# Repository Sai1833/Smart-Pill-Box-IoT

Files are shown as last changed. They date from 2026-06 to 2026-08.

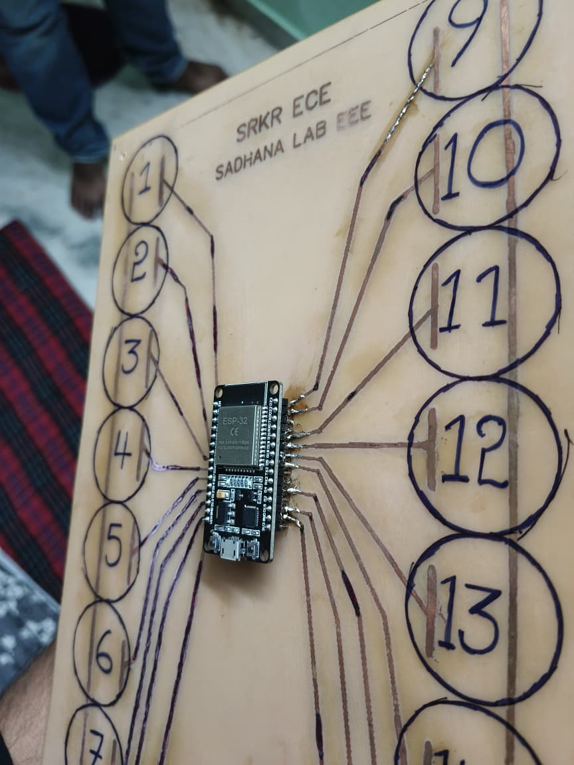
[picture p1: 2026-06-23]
03-PCB_Design/PCB_Hardware/PCB_with_Sholdered_MC_img02.jpg

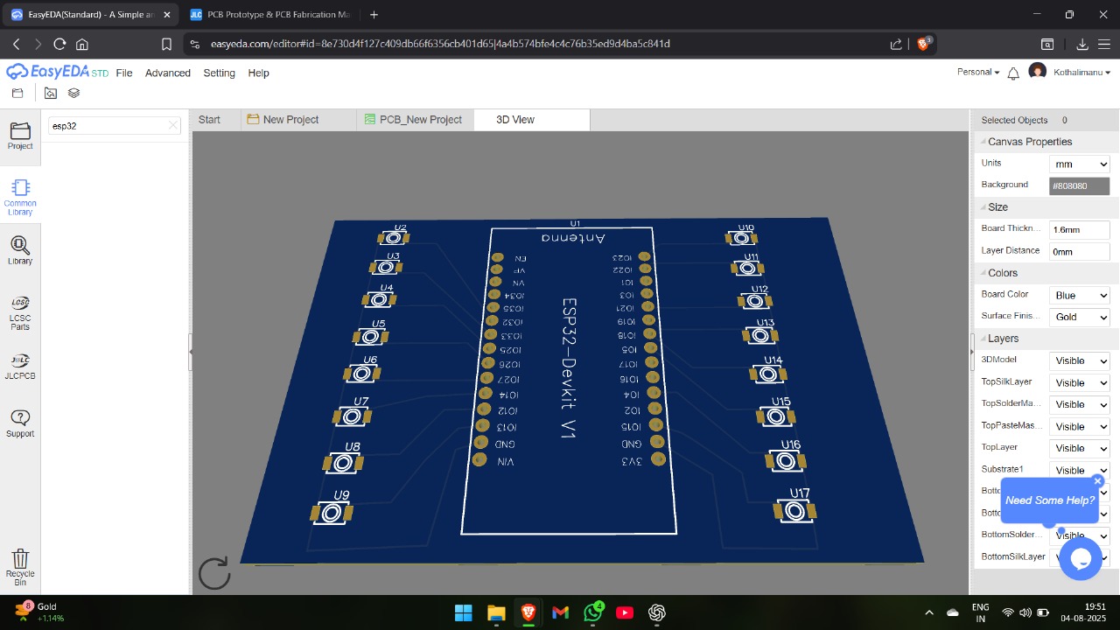
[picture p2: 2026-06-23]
03-PCB_Design/PCB_Simulation/PCB_Design_EasyEda_img01.jpg

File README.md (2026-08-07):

# <p align="center"> 💊 Smart QR Pill Box – IoT Project </p>
## <p align="center">  ESP32 + Bluetooth | End-to-End Product </p>

<p align="center">
  
  
  
  
  
</p>

<p align="center">
  <b>A complete smart medication monitoring system designed, fabricated, assembled, and delivered as a working product.</b><br>
  From sensor research → PCB design & manual fabrication → 3D enclosure → battery integration → final tested unit.
</p>

---

## 🌟 Project Vision

Medication non-adherence is a silent global problem.  
This **Smart QR Pill Box** was built to solve it with a practical, portable, and intelligent American-style design.

The system detects when pills are taken from individual compartments and communicates the status via **Bluetooth**, enabling real-time monitoring and future smart features.

---

## ✨ Key Highlights

| Feature | Details |
|---|---|
| 📦 **10 Pill Bays** | Final production-ready 10-slot design |
| 📡 **Bluetooth Connectivity**  | Real-time status via ESP32 Bluetooth |
| 🔋 **Rechargeable Power** | 3.7V Li-Ion + TP4060 + MT3608 boost |
| 🛠️ **Custom PCB** | Schematic → Layout → Manual etching → Soldering |
| 🖨️ **3D Enclosure** | AutoCAD designed + Laser-cut acrylic finish |
| 📱 **QR Ready** | Designed for QR-based medicine identification |
| 🧪 **Fully Tested** | Office-level validation + final product delivery |

---

## 🧠 How It Works

Pill Taken → Conductive detection (Aluminium foil) → ESP32 senses change → 
Bluetooth transmits status → Companion device / future app receives data

The bottom of each compartment uses aluminium foil as a conductive layer. When a pill bottle or compartment is accessed, the system registers the change and updates the status over Bluetooth.

---

## 🔌 Hardware Stack

- **Microcontroller**: ESP32 DevKit V1
- **Connectivity**: Bluetooth
- **Power System**:
  - 3.7V Li-Ion / LiPo battery
  - TP4060 charging module
  - MT3608 boost converter
- **Detection**: Aluminium foil conductive layer
- **Enclosure**: Custom 3D-designed + Laser-cut acrylic (blue shiny finish)
- **PCB**: Multiple versions designed & fabricated (final 10-slot)

---

## 🛠️ Complete Product Development Journey

| Phase | What Was Done | Outcome |
|---|---|---|
| **Research** | Sensor study, QR concept, LLM/SLM feasibility | Technology selection |
| **Simulation** | Multi-configuration circuits (6/10-way) | Validated sensing methods |
| **Prototyping** | Cardboard models + component assembly | Working proof-of-concept |
| **PCB Design** | Schematic → Layout → Dimension optimization | Multiple PCB revisions |
| **Manual Fabrication** | Toner transfer + FeCl₃ etching + drilling | Hands-on PCB manufacturing  |
| **Assembly** | ESP32 soldering + conductive interface | Fully functional hardware |
| **3D Design** | Base, top, phone holder, slot alignment | Enclosure ready for printing|
| **Power Integration**  | Battery + charging + boost modules | Portable & rechargeable |
| **Final Assembly** | Fitting, adhesives, laser cutting, aesthetics | Product-level finish |
| **Testing & Delivery** | Office testing + courier to Pune office | Successfully delivered |

---

## 💻 Firmware

Located in `07-Code/`

The firmware runs on ESP32 and handles:
- Pill compartment status detection
- Bluetooth communication
- Real-time status reporting

> Update credentials as needed before flashing.

---

## 📸 Project Gallery

Explore the full visual journey:

- **Simulations** → `01-Simulations/`
- **Early Prototypes** → `02-Prototype/`
- **PCB Fabrication Process** → `03-PCB_Design/PCB_Hardware/`
- **3D Designs** → `04-3D_Design/`
- **Final Product** → `05-Final_output/`

---

## 🚀 Future Roadmap

- [ ] Mobile App (Bluetooth pairing + medication schedule)
- [ ] QR code scanning for medicine identification
- [ ] Cloud logging & caregiver dashboard
- [ ] Missed dose alerts & reminders
- [ ] LLM/SLM assisted smart suggestions
- [ ] Multi-user support

---

## 👨‍💻 Contributors

<table>
  <tr>
    <td align="center">
      <a href="https://github.com/Sai1833">
        Sai<br>
        <b>Sai Prakash</b>
      </a>
    </td>
    <td align="center">
      <a href="https://github.com/manohar0306-art">
        Manohar<br>
        <b>Manohar</b>
      </a>
    </td>
    <td align="center">
      <a href="https://github.com/Bhanu-79">
        Bhanu<br>
        <b>Bhanu</b>
      </a>
    </td>
  </tr>
</table>

---

**Internship Details**  
**Company**: Blue Planet Infosolutions Pvt Ltd (Pan Health)  
**Domain**: Embedded System Development  
**Duration**: June 2025 – December 2025  
**Mentor**: Avi Kulkarni Sir  

---

## 📄 Documentation

Full internship completion report and task-wise attachments are available in the  
[`06-Documentations`](./06-Documentations) folder.

---

<p align="center">
  <b>Built with precision. Tested in real conditions. Delivered as a product.</b><br>
  <i>Helping people never miss their medicine — one smart box at a time.</i>
</p>

<p align="center">
  ★ Star this repository if you find it useful ★
</p>

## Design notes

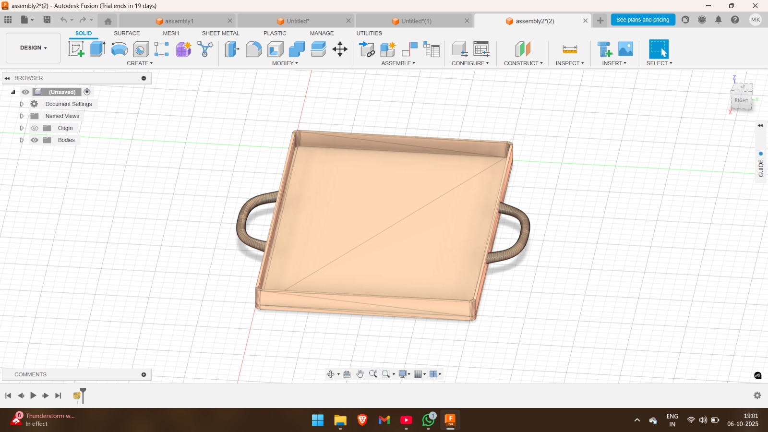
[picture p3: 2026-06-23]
04-3D_Design/Autocad_3D_Design_Bottom_img01.jpg

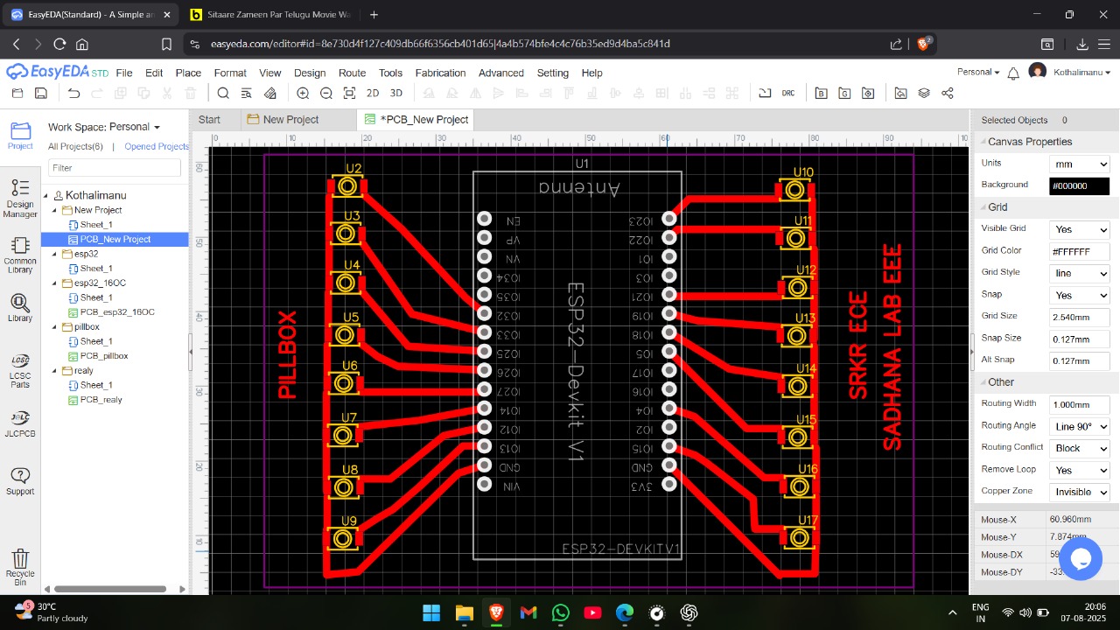
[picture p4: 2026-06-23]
03-PCB_Design/PCB_Simulation/PCB_Design_EasyEda_img03.jpg

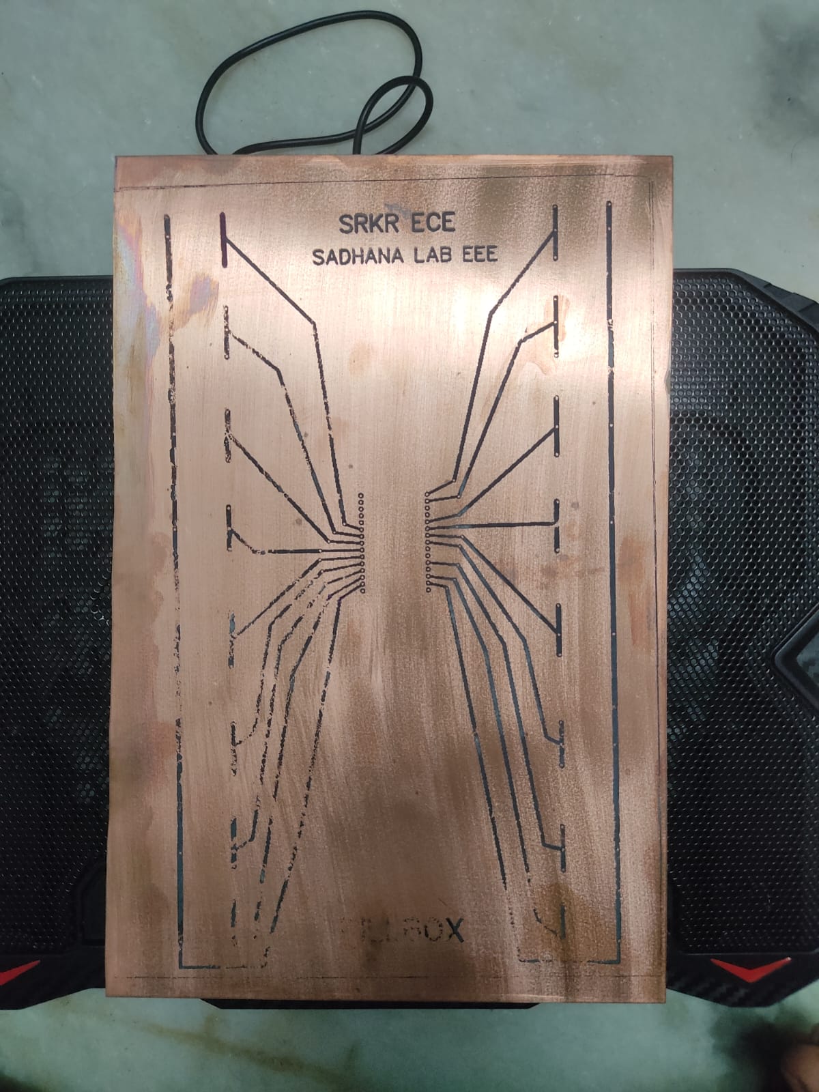
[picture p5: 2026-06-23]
03-PCB_Design/PCB_Hardware/PCB_Before_Removing_Copper_img02.jpg

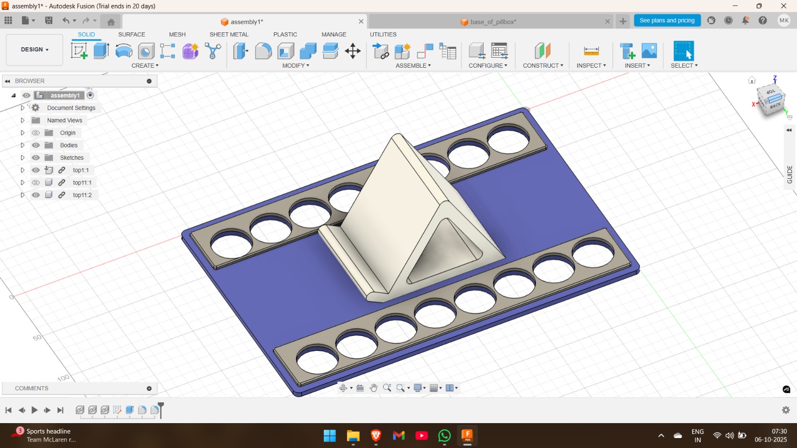
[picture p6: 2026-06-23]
04-3D_Design/Autocad_3D_Design_Top_img01.jpg

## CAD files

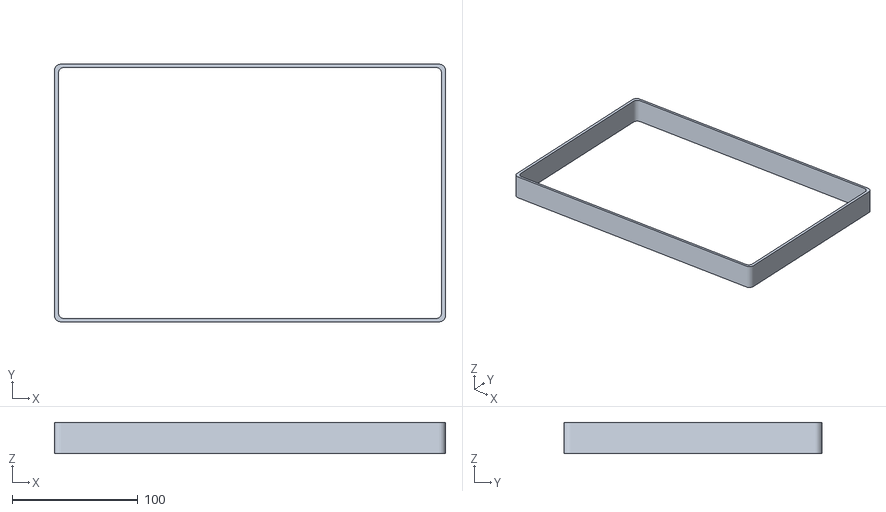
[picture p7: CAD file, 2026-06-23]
04-3D_Design/3D_Design_Cad_Files/center1.stl
311.0 x 205.0 x 25.0

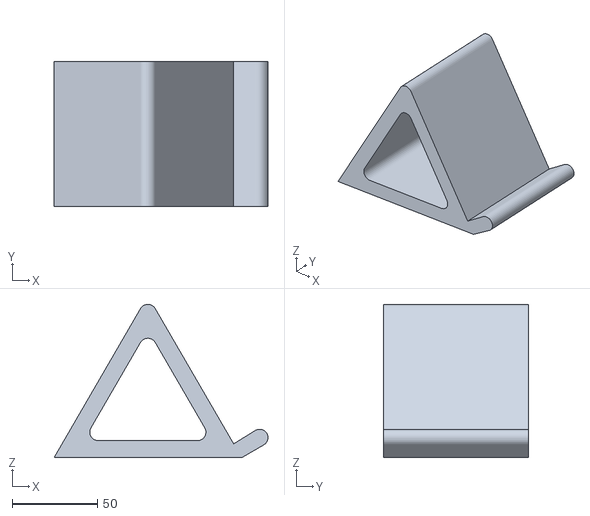
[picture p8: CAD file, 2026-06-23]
04-3D_Design/3D_Design_Cad_Files/top11.stl
125.8 x 85.0 x 90.2

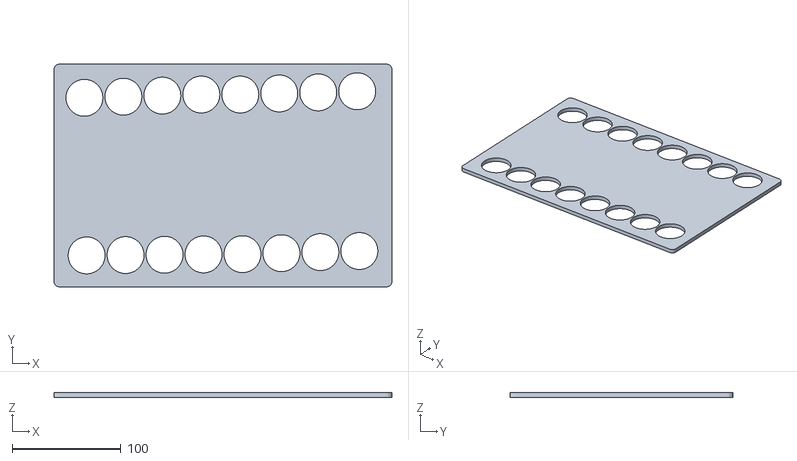
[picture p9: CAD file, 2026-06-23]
04-3D_Design/3D_Design_Cad_Files/top1.stl
311.0 x 205.0 x 4.50

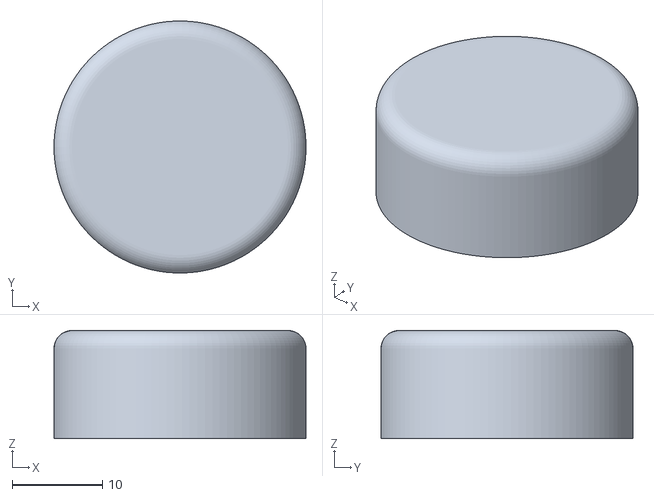
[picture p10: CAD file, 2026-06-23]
04-3D_Design/3D_Design_Cad_Files/bottle_cap.stl
28.0 x 28.0 x 12.0

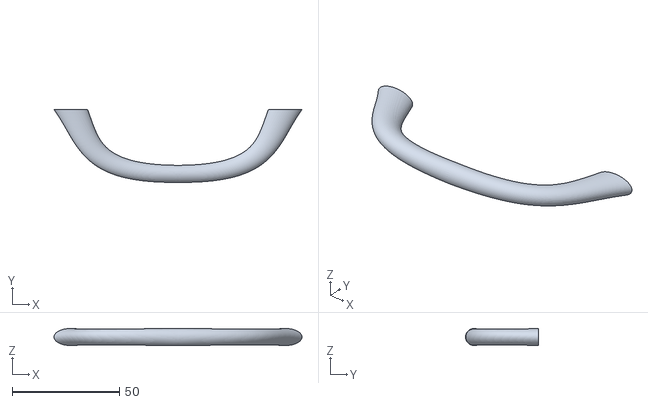
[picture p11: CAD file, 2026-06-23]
04-3D_Design/3D_Design_Cad_Files/handel1.stl
115.7 x 34.0 x 8.00

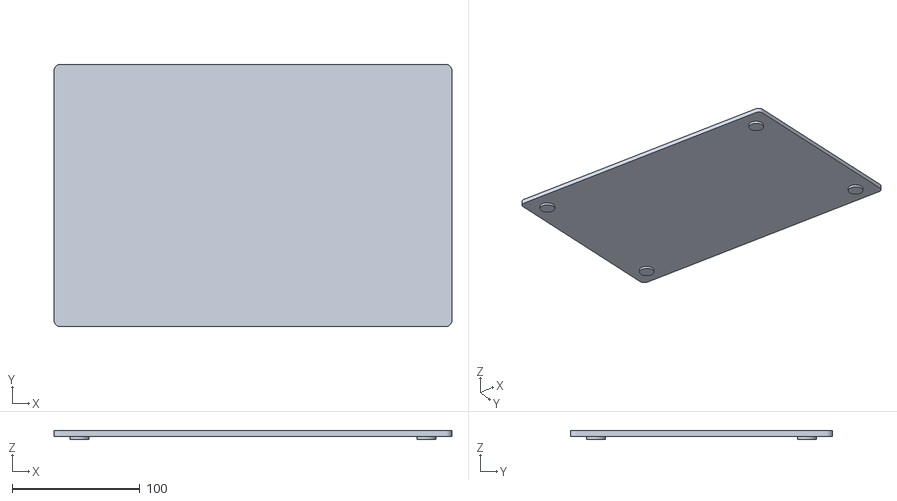
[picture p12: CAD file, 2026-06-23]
04-3D_Design/3D_Design_Cad_Files/bottom1.stl
311.0 x 205.0 x 7.00

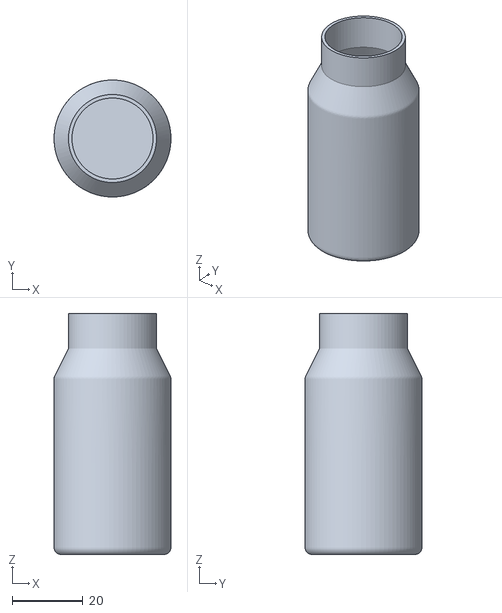
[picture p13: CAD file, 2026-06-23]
04-3D_Design/3D_Design_Cad_Files/bottle_bottom.stl
33.0 x 33.0 x 68.0

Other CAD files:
04-3D_Design/3D_Design_Cad_Files/bottle_bottom.f3z
04-3D_Design/3D_Design_Cad_Files/bottle_cap.f3d
04-3D_Design/3D_Design_Cad_Files/bottom1.f3d
04-3D_Design/3D_Design_Cad_Files/center1.f3d
04-3D_Design/3D_Design_Cad_Files/handel1.f3d
04-3D_Design/3D_Design_Cad_Files/top1.f3d
04-3D_Design/3D_Design_Cad_Files/top11.f3d

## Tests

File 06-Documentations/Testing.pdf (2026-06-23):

REPORT ON TESTING OF SMART PILLBOX By Anishka Tiwari
Date of Testing: 3 December 2025
Team Present: IN Google meet
- Sanvi Kothi
- Manhora
- Sai Prakash
- Anishka

## 1. Introduction

The purpose of this testing session was to evaluate the functioning, connectivity, and reliability of the smart pillbox prototype. The device had been previously shipped to us, and this round of testing was intended to verify basic hardware operation, power system behavior, ESP microcontroller activity, and Bluetooth data communication.

This report documents the observations, issues identified, troubleshooting steps performed, and partial outcomes achieved during the session conducted on 3 December 2025.

## 2. Initial Setup and Power-On Attempts

At the beginning of the test, the team faced difficulty in powering on the smart pillbox. The device did not respond on initial attempts to activate it. After examining the physical structure, the team applied pressure on the yellow lid, suspecting a loose power connection.

Upon pressing the lid and connecting the device to a USB-C charging port, the pillbox displayed a blue activation indicator, confirming that some portion of the power system was active.
However, despite this LED response, the ESP module did not show any signs of functioning, indicating a deeper issue in internal circuitry or power delivery.

## 3. Inspection of Internal Components

To investigate the cause behind the ESP’s non-responsiveness, the team proceeded to open the blue plastic lid of the pillbox.

### 3.1 Findings

- Inside the pillbox, the battery’s ground wire was found to be distorted or loose, most likely due to mishandling or vibration during shipping.
- This faulty ground connection prevented stable power supply to the internal circuit.
- As a result, the ESP microcontroller remained inactive even when the external USB-C port showed a charging indicator.

Identifying this fault confirmed that the issue was hardware-related and not due to firmware malfunction.

## 4. ESP Functionality Testing

To further confirm whether the ESP module was operational, it was removed from the pillbox power line and tested independently.

### 4.1 Procedure

- The ESP board was connected directly to a computer using a USB-B cable.
- This ensured stable external power and allowed direct serial communication for testing.

### 4.2 Result

- The ESP powered on through the USB-B connection.
- This verified that the ESP board itself was not damaged.

Thus, the primary cause of non-functionality was confirmed to be the broken ground connection inside the pillbox.

## 5. Bluetooth Connectivity Tests

### 5.1 Testing via Android Teams App (Bluetooth Admin)

- The team attempted pairing and communication using the Android Teams Bluetooth Admin app.
- While the app could detect the device intermittently, it failed to read or transmit any data.
- This indicated incomplete or unstable Bluetooth communication.

### 5.2 Testing via Custom Smartphone App

- The pillbox was then tested using the custom app developed for the project.
- The custom app successfully detected the Bluetooth module, confirming that the device was broadcasting.
- However, no data packets were received, indicating either:
- a serial communication issue between ESP and Bluetooth module, or
- unstable power supply because of the internal wiring fault.

### 5.3 Testing via Third-Party App: Serial Bluetooth Terminal

- A third-party application named “Serial Bluetooth” from the Play Store was used.
- All available Bluetooth slots were scanned.
- The app initially failed to detect stable internal BC signals, again due to power instability.
- After multiple attempts, partial detections occurred, showing that the module was broadcasting but not fully functional.

These tests collectively verified that the Bluetooth module was functional but could not maintain stable communication due to internal wiring and power issues.

## 6. Conclusion

The testing session on 3 December 2025 revealed that the smart pillbox suffered from a critical internal power connection failure, specifically a distorted or loose battery ground wire caused during shipping. This resulted in:

- ESP microcontroller failing to boot through onboard power
- Unstable Bluetooth communication
- Intermittent device activation despite USB-C charging indicator

Independent testing confirmed that the ESP and Bluetooth module themselves are functional. The root cause of malfunction is therefore the damaged internal ground wiring.

Next Steps / Recommendations

1. Repair the ground wire connection and secure all internal wiring with protective insulation.
2. Add shock-proof padding inside the pillbox to prevent shipping-related damage.
3. Retest the ESP’s power-on, Bluetooth communication, and app data transmission after repair.
4. If available, update firmware to log power failures for easier diagnostics.
5. Perform a complete end-to-end test once the internal circuit is stable.

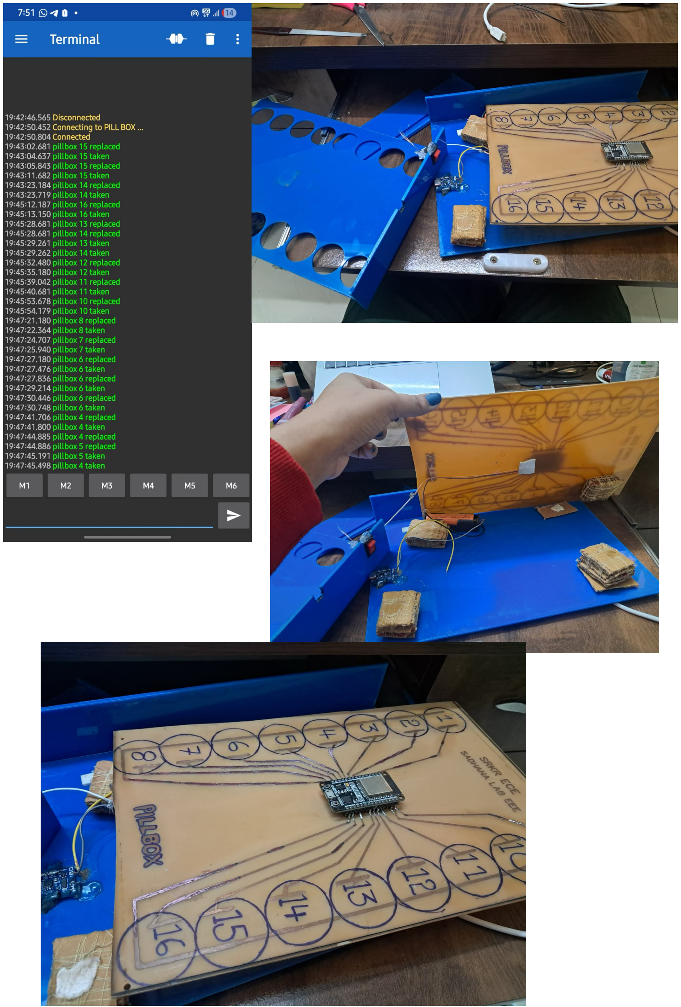
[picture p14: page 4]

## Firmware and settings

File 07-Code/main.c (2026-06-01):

#include <WiFi.h> 
#include <WebServer.h> 
const char* ssid = "YOUR_WIFI_NAME"; 
const char* password = "YOUR_WIFI_PASSWORD"; 
WebServer server(80); 
const int buttonPins[16] = {32, 33, 25, 26, 27, 14, 12, 13, 23, 22, 21, 19, 18, 5, 4, 15}; 
void handleRoot() { 
String message = "Pill Box Status:\n\n"; 
for (int i = 0; i < 16; i++) { 
bool isTaken = digitalRead(buttonPins[i]) == HIGH;  
message += "Slot " + String(i + 1) + ": " + (isTaken ? "TAKEN" : "REPLACED") + "\n"; 
} 
server.send(200, "text/plain", message); 
} 
void setup() { 
Serial.begin(115200); 
for (int i = 0; i < 16; i++) pinMode(buttonPins[i], INPUT_PULLUP); 
WiFi.begin(ssid, password); 
while (WiFi.status() != WL_CONNECTED) { delay(500); Serial.print("."); } 
Serial.println("\nConnected! IP: " + WiFi.localIP().toString()); 
server.on("/", handleRoot); 
server.begin(); 
} 
void loop() { 
server.handleClient(); 
}

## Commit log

2026-06-23 Create prototype
2026-06-24 Rename WhatsApp Image 2025-10-26 at 8.55.23 PM.jpeg to final_output_charging&switch_img02.jpg
2026-06-24 Rename WhatsApp Image 2025-10-26 at 8.55.08 PM (1).jpeg to PCB_Before_Removing_Copper_img01.jpg
2026-06-24 Rename WhatsApp Image 2025-10-26 at 8.55.09 PM.jpeg to PCB_Before_Removing_Copper_img02.jpg
2026-06-24 Rename WhatsApp Image 2025-10-26 at 8.55.04 PM.jpeg to PCB_Design_EasyEda_img01.jpg
2026-06-24 Rename WhatsApp Image 2025-10-26 at 8.55.05 PM (1).jpeg to PCB_Design_EasyEda_img02.jpg
2026-06-24 Rename WhatsApp Image 2025-10-26 at 8.55.05 PM (2).jpeg to PCB_Design_Printout_img01.jpg
2026-06-24 Rename WhatsApp Image 2025-10-26 at 8.55.05 PM.jpeg to PCB_Design_EasyEda_img03.jpg
2026-06-24 Rename WhatsApp Image 2025-10-26 at 8.55.06 PM (1).jpeg to PCB_Design_Printout_img02.jpg
2026-06-24 Rename WhatsApp Image 2025-10-26 at 8.55.06 PM.jpeg to PCB_Design_Printout_img03.jpg
2026-06-24 Rename WhatsApp Image 2025-10-26 at 8.55.07 PM.jpeg to PCB_Design_Printout_img04.jpg
